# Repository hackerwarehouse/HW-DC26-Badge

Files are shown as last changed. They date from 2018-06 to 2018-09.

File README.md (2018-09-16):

# HW-DC26-Badge
This is the project page for the Hacker Warehouse electronic badge that was made for DEF CON 26.



## Badge Hardware Specs
* ESP32
* Atmel 32u4
* 96×64 Graphic Full Color OLED Display
* 14x Mini NeoPixel RGB LEDs
* 4 tactile buttons
* 8 Mb Storage
* 2x2 "[Shitty Add-on](https://hackaday.io/project/52950-defcon-26-shitty-add-ons "Shitty Add-on")" support
* Powered via 2 AA batteries or USB

## Badge Functions
* HID Arsenal
	* Ducky script compatible payloads (Windows and Linux demo payloads included)
	* Expanded ducky commands to support mouse movement and clicks
	* Static strings (yubico like)
	* Mouse jiggler (anti screensaver)
	* Time-based One-Time Password and HMAC-based One-Time Password (Google Authenticator mode /w keyboard insertion on demand)
* WiFi Tools
	* 802.11 channel activity monitor
	* Access point scanner / Open AP detector
	* Packet Monitor and Deauth sniffer
	* Can act as a client or access point
	* Webserver (edit filesystem files, trigger payloads remotely)
	* NTP client
* LED patterns and OLED graphics
* Misc. extras

## Usage Instructions
### Power Switch
In order to turn on the device, it must be powered via 2 AA batteries or USB. The main power switch is between the eyes.

### Buttons / UI


Up and Down is on the left side of the OLED, and Left and Right is on the right side of the OLED. From left most to right:  Down / Up / Left / Right

In order to go into a menu or run a program, click the right button. To exit most applications, click the left button. Some programs like the snake game require all 4 buttons so there is no way to clean exit, a power cycle is needed. 

### Keyboard and Mouse Payloads
When the badge is connected to a computer through the USB port, it can act as a HID device. The most common uses of that device class is keyboards and mice. Through use of the Ducky language and expanding on it to support mouse movement, the badge can trigger these scripts on demand. 

#### Via Hardware Menu
Navigate to the HID Arsenal menu, then select either the Windows or Linux Payloads menu option, depending on your target device. In the next submenu, there are five slots for payloads and pressing the right button triggers them. The slots are configurable via win.json and lin.json which defines the payload name and file location.

#### Via Webserver
Assuming the Webserver is running (via Server Tools -> Webserver Start), navigate to 10.0.5.1. Authenticate via the credentials on the OLED. You can remotely trigger the stored payloads or write on demand payloads via this interface. The stored payloads read the same win.json and lin.json files. 

### Static Strings
This mode is something like the yubico device. It is simply a static string that you can utilize with another password. This is a method of two factor authentication as the static string would be likely long and complex. Disclaimer: There is no security mechanism in place if someone were to obtain the hardware and this isn't a FIPS certified device.

### Mouse Jiggler
This mode is utilized if you have a device that you don't want the screen saver to be triggered. The mouse will move every few seconds in a defined pattern. This is useful if you have a device that forces a screensaver or device lock after x idle time. 

### Google Authenticator
This mode requires the badge to be connected to an access point that has internet connectivity so it can reach a time server as there is no RTC on the device itself. In the WiFi client tools menu, connect to an AP and make sure NTP is running. From there, in the HID Arsenal menu select the 'Google Auth (TOTP)' submenu. The six digit time based unique code will refresh every seconds. Press the right button to insert that set of digits automatically assuming the badge is connected through USB. 



### Webserver
Navigate to WiFi Server Tools -> Webserver Start. You can access the webserver if running an AP or if connected. The pages are protected through basic authentication, username and password generated dynamically and is provided on the screen.

### Blinky
There are 40+ LED patterns included. We've included our favorites set in a 5 second rotation. You can also trigger each type of pattern individually. 

### Other Modes
There are no hidden modes, but there are a few areas we didn't cover in this set of docs. Explore. 

## Configuration / Customization
### Settings menu in OLED UI
After feedback from last year on brightness settings, there are individual settings for OLED and LED brightness. Region setting is related to WiFi channel scanning.

### JSON configuration files
There are 4 different json files in SPIFFS. There are a couple ways to edit these files and get them loaded on the badge, but the easiest is through the webserver.
1. config.json = Main device configuration. Includes parameters such as LED and OLED brightness settings, ssid/password if connecting to a wireless client network, region information, and google auth HMAC. 
2. lin.json / win.json = Configuration files for the Linux and Windows KB/M payloads. 
3. static.json = Configuration file for the stored static strings. 

### Google Authenticator
If you do not have a 2 factor code from Google already, follow these steps to set obtain one and change your security settings: 
https://myaccount.google.com/security -> Signing into Google -> 2 Factor Authentication -> Authenticator App -> iphone -> click the 'Can't scan it' button and you will get a string of text that looks like this (and remember that your code will be different than this example):



Take that text, remove all the spaces, change the letter casing to all upper case, then 
input the text into config.json

## Compiling Instructions
These instructions will get you a copy of the project up and running on your local machine.
### Prerequisites
What things you need to install the software and how to install them
```
1. Arduino / compiler
2. SparkFun Pro Micro v3 com driver
https://learn.sparkfun.com/tutorials/pro-micro--fio-v3-hookup-guide/installing-windows
https://learn.sparkfun.com/tutorials/pro-micro--fio-v3-hookup-guide/installing-mac--linux
3. Libraries
  https://raw.githubusercontent.com/sparkfun/Arduino_Boards/master/IDE_Board_Manager/package_sparkfun_index.json
  https://github.com/adafruit/Adafruit_NeoPixel
  https://github.com/adafruit/Adafruit-GFX-Library
  https://github.com/adafruit/Adafruit_CircuitPlayground
  https://github.com/kitesurfer1404/WS2812FX
  https://github.com/me-no-dev/ESPAsyncWebServer
  https://github.com/me-no-dev/AsyncTCP
  https://github.com/bblanchon/ArduinoJson
  https://github.com/me-no-dev/arduino-esp32fs-plugin
  Manually copy the SSD_13XX and qMenuSystem folders to Arduino libraries folder. We included a snapshot of the other libraries used in case newer versions break our code.
4. 3.3v FTDI serial cable
5. and of course a Hacker Warehouse DC26 Badge
```
### Compiling / Flashing Atmel Code
* Set the board to SparkFun Pro Micro
* Set the processor as ATmega32u4 3.3v and NOT the 5v one

### Compiling / Flashing ESP Code
* Set the board to SparkFun ESP32 Thing

#### Programming through FTDI port
1. Flash the atmel with the 'atmel-esp32ftdi-pin7' code first, as this toggle pin 7 and the rx/tx switch to change the serial port communiction to the FTDI port
2. Connect FTDI cable to the board while holding the left button down (which is on the right side, top button)
3. Upload code. Speed setting doesn't really matter, we've been using 921600.
4. To put the atmel back to its original state, program 'atmel-km-relay' the code to it.

#### Programming through USB port / Atmel
Pass through programming doesn't work at the time of writing. Communication is passed through, but something is holding up the ESP32 from fully going into the programming mode

### Uploading SPIFFS files
The keyboard/mouse payloads, configuration files, webserver files are all files that are loaded into a special section in storage marked as SPIFFS. While still having pin 7 set to allow for the FTDI connection, use the 'ESP32 Sketch Data Upload' function in the tools menu. This will compress and compile all the files in the 'data' folder, and upload it. 

## Expanding on your own
### Adding to menu
* See files HW-DC26-Badge.ino and mainmenu.h
* Look at the main switch statement in the .ino file
* Look any of the mainmenu.h examples for how it corresponds to the display

### Button mapping / Escape code
* See files HW-DC26-Badge.ino and blinky.cpp 
* Button mapping is in the beginning of the .ino file
* Look at the LED_Flashlight function for an example of button usage and how to quit the loop and go back to main menu

## Background / timeline of badge development
* Second custom hardware / electronics project trying to improve upon the things we learned from last year
	* Changed from the ESP8266 to the newer ESP32 so we could leverage prior code and focus on enhancements 
	* Added an LDO regulator so badge or connected computer doesn't freak out on voltage
* 3 hardware revisions = 2 prototype runs = 4-5 months
	* The hardware revisions this year were minor in comparison to last year. It was mainly due to the 2x2 Shitty Add-on and orientation of the connector
	* Tried to start earlier (lesson learned last year) but scheduling conflicts put us back to essentially the same timeline as last year
* 5 week code sprint before code needing to be frozen for mass badge flashing
	* This was a massive improvement from last year from a time / rush perspective
	* Still wanted to add more into it such as BLE, but ram out of storage and ram. 

## Authors / Contributors
* **Garrett Gee**

## Acknowledgments
* Hat tip to anyone who's code was used, looked at, referenced, etc
* All the supporters of this project

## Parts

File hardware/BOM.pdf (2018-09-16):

Quantity | Description | Part Number | Alternative Part Number | Reference Designator
2 | 22PF 50V NP0 0603 Capacitor | CL10C220JB8NNNC | C1608C0G1H220G080AA | C2, C3
2 | 10uf Tantalum Capacitor 1206 16V 20% | F931C106MAAAJ6 | F931C106MAA | C4, C8
1 | 4.7UF 16V X5R 0603 | C1608X6S1C475K080AC | | C46
4 | 10uF 25V 20% 0603 Capacitor | CL10A106MA8NRNC | | C6, C9, C10, C24
1 | .01uf/10nf 100V 0603 10% Capacitor | CL10B103KC8NNNC | | C20
5 | 1uf 16V 10% 0603 Capacitor | CC0603MRY5V6BB105 | CL10A105KO8NNNC | C1, C29, C44, C45, C47
22 | 0.1uf 25V 10% 0603 Capacitor | 06033C104KAZ2A | CL10B104KA8NNNC | C5, C7, C21, C23, C25, C26, C27, C28, C30, C31, C32, C33, C34, C35, C36, C37, C38, C39, C40, C41, C42, C43
1 | 3.3nf 16V 10% 0603 Capacitor | VJ0603Y332KXJCW1BC | | C19
1 | 100pf/0.1nf 100V 0603 Capacitor | GRM1885C2A101JA01D | | C22
2 | 10pF Â±0.25pF 50V Ceramic Capacitor C0G, NP0 0603 | C1608C0G1H100C080AA | | C13, C16
1 | 5.6pF Ceramic Capacitor +-0.5pF 50V 0603 | CL10C5R6DB8NNNC | | C11
2 | CAP CER 15PF 50V C0G/NPO 0603 | CC0603JRNPO9BN150 | | C14, C15
1 | CAP CER 2.4PF 50V C0G/NP0 0603 | CL10C2R4CB8NNNC | | C12
2 | CAP CER 270PF 50V X7R 0603 | CL10B271KB8NNNC | | C17, C18
1 | SS1P3L Schottky Diode 30V 1A | SS1P3L-M3/84A | | D3
2 | DIODE SCHOTTKY 40V 1A SOD123 | B140HW-7 | | D2, D5
1 | Diode Standard 75V 150mA SOD-323F | 1N914BWS | | D1
14 | 3535 RGB Addressable LED | SK6812MINI | | LED1, LED2, LED3, LED4, LED5, LED6, LED7, LED8, LED9, LED10, LED11, LED12, LED13, LED14
1 | DPDT Slide Switch (On/Off) SMT | AYZ0202AGRLC | | S1
4 | Black Momentary Push Button - SMD | TL3301NF100QG | | U$1, U$2, U$3, U$4
1 | USB Micro-B RECPT SMD Connector | 10118194-0001LF | | U$6
1 | Battery Holder 2-AA TH | BC2AAPC | | U$5
2 | 2x2 Pin 4P 2.54mm Double Row Female Straight Header Pitch Socket Pin Strip | | | JP1, JP2
1 | ATMEGA32U4-MU Microcontroller QFN | ATMEGA32U4-MU | | U4
1 | LED Driver Regulator 1A SOT23-5 | FAN5331SX | | U1
1 | IC REG LINEAR 3.3V 500MA SOT223 | MIC5209-3.3YS-TR | | U$7
2 | IC MUX/DEMUX 2X1 6TSSOP | 74LVC1G3157GW,125 | | U$8, U$9
1 | ESP3212 | ESP3212 | | U2
1 | IC OR CTRLR SRC SELECT 8SON | TPS2113ADRBR | | U$10
1 | IC FLASH 64MBIT SPI 8SOIC W25Q64JVSSIM TR | W25Q64JVSSIM TR | | U5
1 | 10 uH Inductor 1.8A 5028 | SRU5018-100Y | | L1
1 | FIXED IND 2.7NH 300MA 100 MOHM | HK16082N7S-T | | L2
1 | 0.95 inch (96 x 64) Pixel Full Color Passive OLED LCD | UG-9664HDDAG01 | | LCD1
3 | 100K Resistor 0603 1/10W 5% | RC0603JR-07100KL | | R2, R6, R12

## Hacker Warehouse 2018 DC26 Badge v1.1 BOM

Quantity | Description | Part Number | Alternative Part Number | Reference Designator
1 | 1K OHM 5% 1/10W 0603 Resistor | ERJ-3GEYJ102V | RC0603JR-071KL | R13
6 | 10K Resisitor 0603 1/10W 5% | RC0603JR-0710KL | | R1, R3, R5, R7, R8, R10
1 | 1M Resistor 0603 1/10W 1% | RC0603FR-071ML | | R4
2 | 22 ohm Resistor 0603 1/10W 5% | RC0603JR-0722RL-S | | R14, R15
2 | RES SMD 20K OHM 1% 1/10W 0603 | RC0603FR-0720KL | | R9, R11
1 | 8.0 MHz Crystal 5 mm x 3.2 mm | ABM3B-8.000MHZ-B2-T | | Y1
1 | 32.768 KHz Crystal FC-135 32.7680KA-A3 | ABS07-32.768KHZ-T | FC-135 32.7680KA-A3 | X2
1 | Crystal 26MHz 3.2 x 2.5 | TSX-3225 26.0000MF09Z-AC0 | | Y2

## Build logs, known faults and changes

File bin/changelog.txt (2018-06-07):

HW-DC26-Badge-20180603.bin
 New
  - Webserver via ESPAsyncWebServer and AsyncTCP libraries
  - SPIFFS live editor / file upload via webserver
  - Firmware update via webserver
  - Live Keyboard/Mouse payload via webserver
  - Stored Keyboard/Mouse payloads can be triggered via webserver
 Updates / Tweaks
  - KB injection call does basic checks first before attempting to run
  - Early Supporters list
 Known Bugs / Limitations
  - MINOR: NTP_OFFSET is an int and some timezone offsets are greater than that size. NTP library itself needs fixing. Doesn't impact TOTP
  - MINOR: SPIFFS file writing /w file name length and directories. Doesn't impact demo payloads
  - MINOR: max file name length for payloads is 40 chars
  - MINOR: dynamic menu names have max length of 15 chars
  - ?    : stability due to lack of ram available for large tasks (SPIFFS live editor)
 Compile notes:
   Sketch uses 843890 bytes of program storage space. Maximum is 1310720 bytes.
   Global variables use 43216 bytes (14%) of dynamic memory, leaving 251696 bytes for local variables. Maximum is 294912 bytes.

HW-DC26-Badge-20180522.bin
 New
  - Custom KB injection naming/ordering in menu via json files
 Updates / Tweaks
  - Moved static strings configuration to its own json file
 Fixed
  - Static strings injection
 Known Bugs / Limitations
  - MINOR: NTP_OFFSET is an int and some timezone offsets are greater than that size. NTP library itself needs fixing. Doesn't impact TOTP
  - MINOR: SPIFFS file writing /w file name length and directories. Doesn't impact demo payloads
  - MINOR: max file name length for payloads is 40 chars
  - MINOR: dynamic menu names have max length of 15 chars
 Compile notes:
   Sketch uses 764814 bytes of program storage space.
   Global variables use 42696 bytes (14%) of dynamic memory, leaving 252216 bytes for local variables. Maximum is 294912 bytes.

HW-DC26-Badge-20180515.bin
 New
  - AP start/stop/info display service
  - Static strings kb injection module /w custom names via config.json
 Updates / Tweaks
  - Google Auth code can now be inserted for user via usb kb injection if pressing right button while in app
  - Graphic image updates
  - Change loop structure on majority of functions
  - Ducky compatible parser for kb injection
  - Standardized mouse button and movement triggers
 Known Bugs / Limitations
  - MINOR: NTP_OFFSET is an int and some timezone offsets are greater than that size. NTP library itself needs fixing. Doesn't impact TOTP
  - MINOR: SPIFFS file writing /w file name length and directories. Doesn't impact demo payloads
 Compile notes:
   Sketch uses 762986 bytes of program storage space.
   Global variables use 42064 bytes (14%) of dynamic memory, leaving 252848 bytes for local variables. Maximum is 294912 bytes.

HW-DC26-Badge-20180508.bin
 New
  - Time based One Time Password (TOTP) - make sure NTP is running for clock sync
  - Google Authenticator using TOTP via user key in spiffs
 Fixed
  - Internet connection logic
  - NTP server connection issue
  - Flashlight lowest mode
 Known Bugs / Limitations
  - MINOR: NTP_OFFSET is an int and some timezone offsets are greater than that size. NTP library itself needs fixing. Doesn't impact TOTP
 Compile notes:
   Sketch uses 756498 bytes of program storage space. 
   Global variables use 41832 bytes (14%) of dynamic memory, leaving 253080 bytes for local variables. Maximum is 294912 bytes.

HW-DC26-Badge-20180506.bin
 New
  - Keyboard sequence pass through from esp32 to 32u4 for keyboard injection on computer
  - Mouse sequence pass through from esp32 to 32u4 for mouse injection on computer
  - NTP client - pacific time default for Las Vegas
 Updates / Tweaks
  - File and menu organization to support feature expansion
  - Internet ssid / password settings in spiffs
  - Optimized connection attempts to internet ssid
 Compile notes:
   Sketch uses 754658 bytes of program storage space.
   Global variables use 41648 bytes (14%) of dynamic memory, leaving 253264 bytes for local variables. Maximum is 294912 bytes.

HW-DC26-Badge-20180505.bin
 Updates / Tweaks
  - Flashlight now starts at lowest setting
  - Snake game added back in
  - Button echo added back in
  - Keyboard demo added back in
 Fixed
  - String importing on json config file
 Compile notes:
   Sketch uses 743770 bytes of program storage space. 
   Global variables use 41452 bytes (14%) of dynamic memory, leaving 253460 bytes for local variables. Maximum is 294912 bytes.

HW-DC26-Badge-20180504.bin
 Updates / Tweaks
  - Added back in Channel AP Scanner
  - Display code logic
  - Added back in and updated packet / deauth sniffer
 Compile notes:
   Sketch uses 736418 bytes of program storage space.
   Global variables use 41260 bytes (13%) of dynamic memory, leaving 253652 bytes for local variables. Maximum is 294912 bytes.

HW-DC26-Badge-20180503.bin
 New
  - spiffs for configuration save. removed eeprom versions as esp32 eeprom support is currently buggy
  - Firmware OTA update
 Updates / Tweaks
  - Added back in AP Scanner
  - Split out oled and led brightness settings
  - Changed UX on oled and led brightness settings for quicker user feedback
 Fixed
  - Oled on power on
  - LEDs that randomly stay on at power on
 Compile notes:
   Sketch uses 726558 bytes of program storage space. 
   Global variables use 40508 bytes (13%) of dynamic memory, leaving 254404 bytes for local variables. Maximum is 294912 bytes.

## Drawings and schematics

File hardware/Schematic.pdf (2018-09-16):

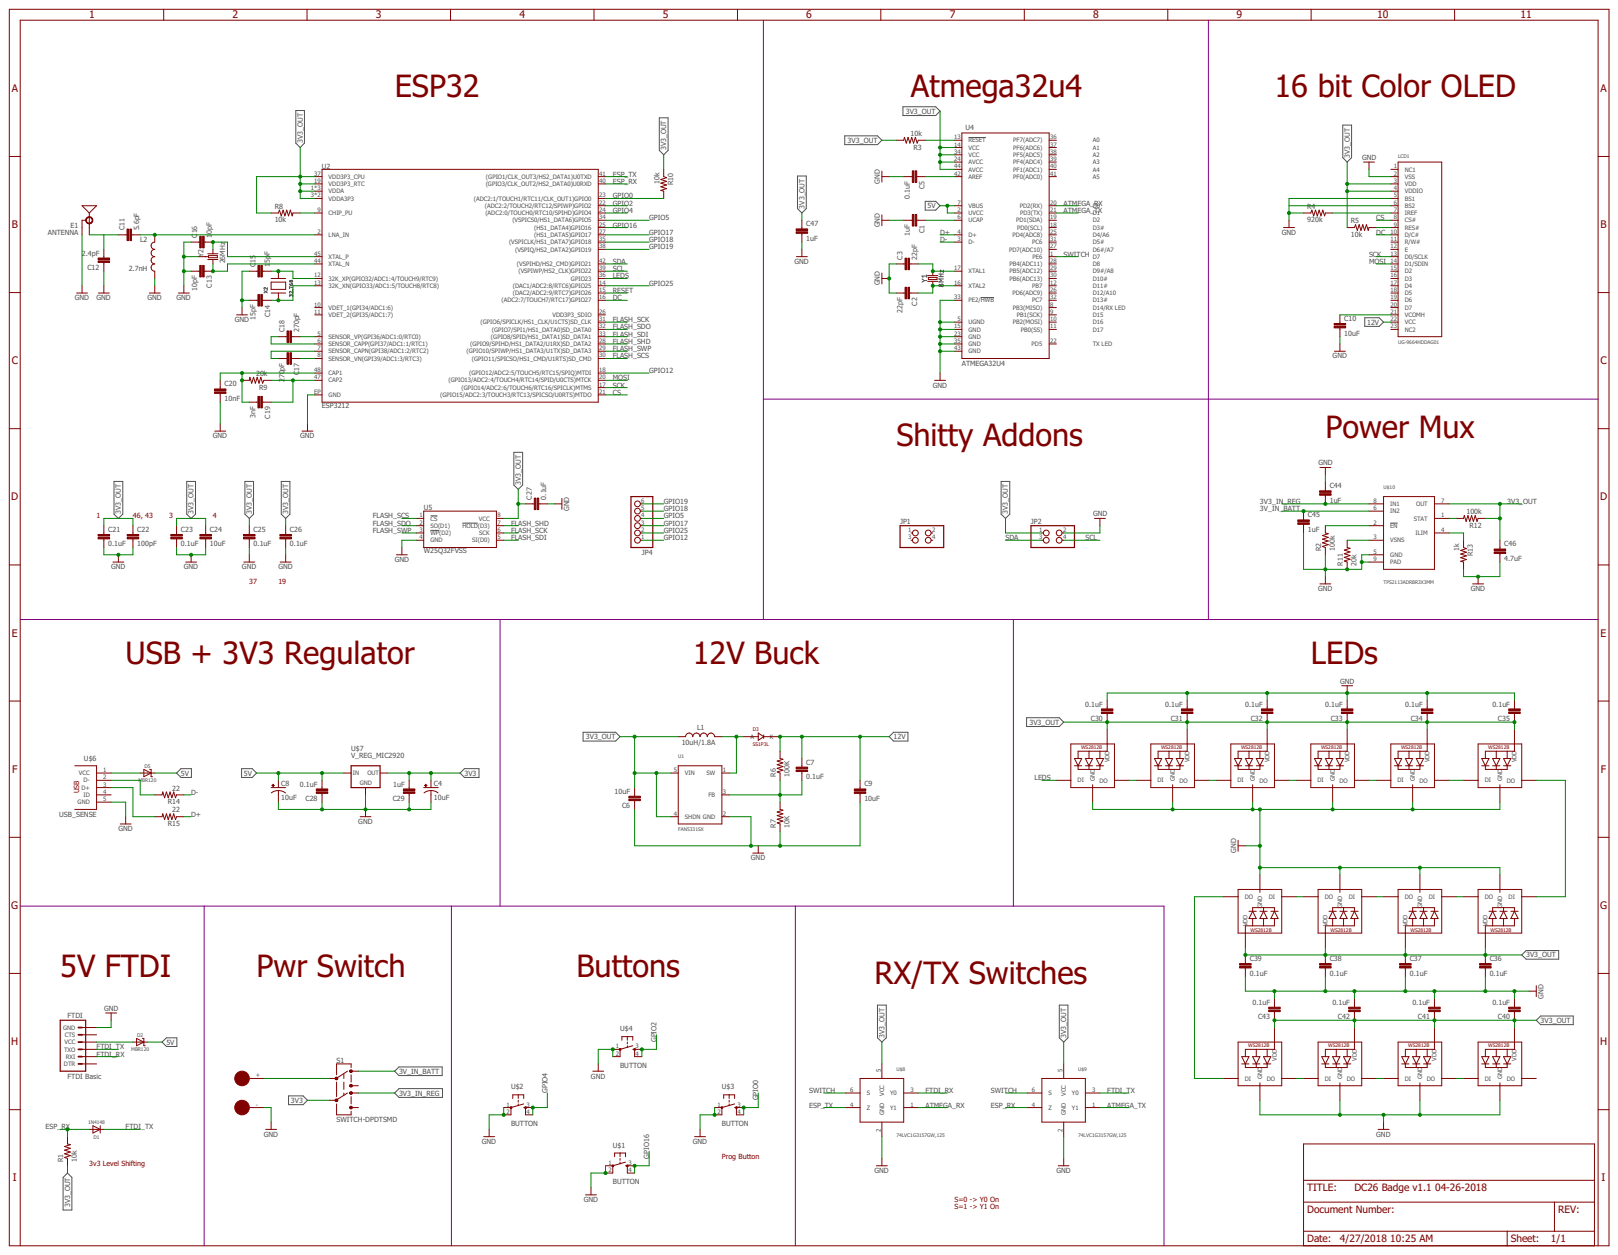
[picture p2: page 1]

ESP32 | Atmega32u4 | 16 bit Color OLED

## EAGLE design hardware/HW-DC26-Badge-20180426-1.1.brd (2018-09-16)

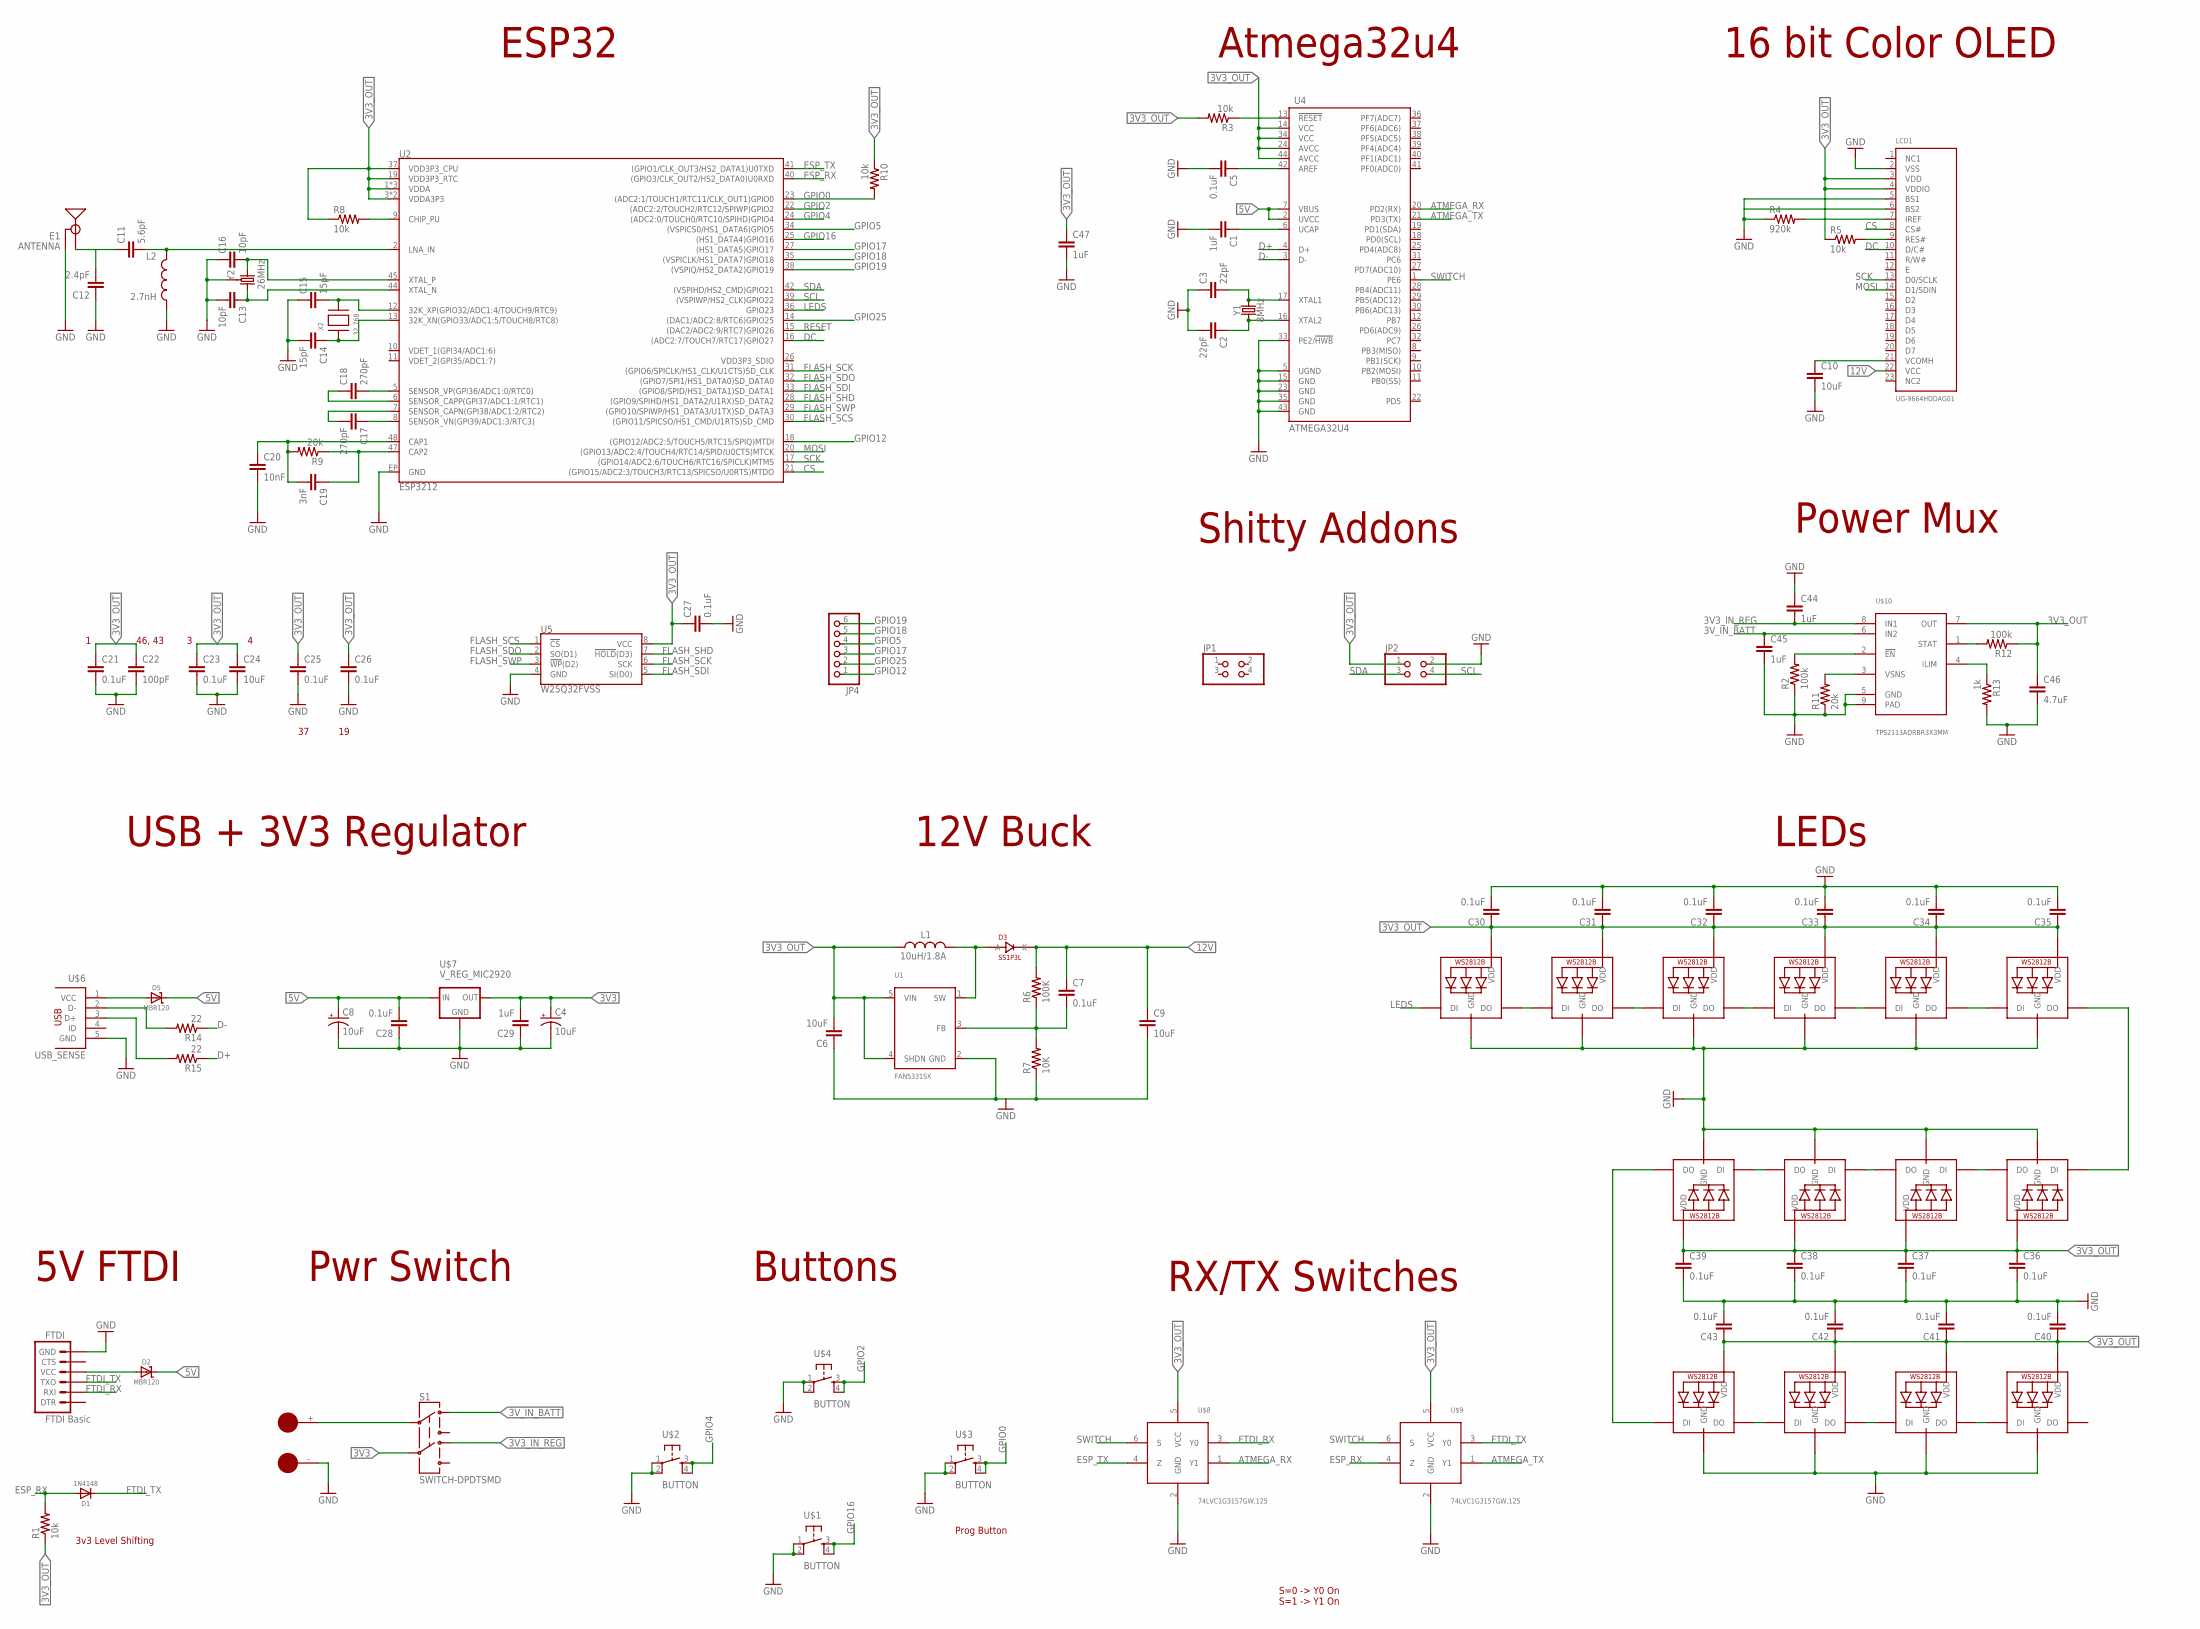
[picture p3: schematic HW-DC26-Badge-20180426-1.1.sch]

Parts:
C1, C29, C44, C45, C47: 1uF; CAP0603
C2, C3: 22pF; CAP0603
C4, C8: 10uF; EIA3216
C5, C7, C21, C23, C25, C26, C27, C28, C30, C31, C32, C33, C34, C35, C36, C37, C38, C39, C40, C41, C42, C43: 0.1uF; CAP0603
C6, C9, C10, C24: 10uF; CAP0603
C11: 5.6pF; CAP0603
C12: 2.4pF; CAP0603
C13, C16: 10pF; CAP0603
C14, C15: 15pF; CAP0603
C17, C18: 270pF; CAP0603
C19: 3nF; CAP0603
C20: 10nF; CAP0603
C22: 100pF; CAP0603
C46: 4.7uF; CAP0603
D1: 1N4148; SOD-323
D2, D5: MBR120; SOD-123
D3: SS1P3L; DO220AAL
E1: ANTENNA; TRACE_ANTENNA_2.4GHZ_25.7MM_TUNED
FTDI: FTDI Basic; 1X06
JP1, JP2: PINHD-2X2; 2X02
JP4: PINHD-1X6; 1X06
L1: 10uH/1.8A; SRU5028
L2: 2.7nH; 0603
LCD1: UG-9664HDDAG01; UG-9664HDDAG01_WRAPAROUND
LED1, LED2, LED3, LED4, LED5, LED6, LED7, LED8, LED9, LED10, LED11, LED12, LED13, LED14: WS2812B3535; LED3535
R1, R3, R5, R8, R10: 10k; RES-0603
R2, R12: 100k; RES-0603
R4: 920k; RES-0603
R6: 100K; RES-0603
R7: 10K; RES-0603
R9, R11: 20k; RES-0603
R13: 1k; RES-0603
R14, R15: 22; RES-0603
S1: SWITCH-DPDTSMD; AYZ0202
U1: FAN5331SX; SOT23-5
U2: ESP3212; QFN48-0.4MM
U4: ATMEGA32U4; QFN-44-NOPAD_1:1-OUTFAKES
U5: W25Q32FVSS; SOIC-8
U$1, U$2, U$3, U$4: BUTTON
U$5: BAT_HOLD; AA
U$6: USB_SENSE; USB-MICRO-TH-SUPPORT
U$7: V_REG_MIC2920; SOT223
U$8, U$9: 74LVC1G3157GW,125; SOT-363
U$10: TPS2113ADRBR3X3MM; 8-VDFN
X2: 32.768; XTAL3215
Y1: 8MHz; CRYSTAL-SMD-5X3.2-4PAD
Y2: 26MHz; CRYSTAL-SMD-3.2X2.5

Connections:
3V3: C4.A (+), C29.2, S1.5, U$7.3 (OUT)
3V3_IN_REG: C44.2, S1.4, U$10.8 (IN1)
3V3_OUT: C6.2, C21.1, C22.1, C23.1, C24.1, C25.1, C26.1, C27.1, C30.1, C31.1, C32.1, C33.1, C34.1, C35.1, C36.1, C37.1, C38.1, C39.1, C40.1, C41.1, C42.1, C43.1, C46.1, C47.1, JP2.1, L1.1, LCD1.3 (VDD), LCD1.4 (VDDIO), LED1.2 (VDD), LED2.2 (VDD), LED3.2 (VDD), LED4.2 (VDD), LED5.2 (VDD), LED6.2 (VDD), LED7.2 (VDD), LED8.2 (VDD), LED9.2 (VDD), LED10.2 (VDD), LED11.2 (VDD), LED12.2 (VDD), LED13.2 (VDD), LED14.2 (VDD), R1.1, R3.2, R5.1, R8.1, R10.1, R12.1, U1.4 (SHDN), U1.5 (VIN), U2.1 (VDDA), U2.3 (VDDA3P3), U2.4 (VDDA3P3), U2.19 (VDD3P3_RTC), U2.37 (VDD3P3_CPU), U2.43 (VDDA), U2.46 (VDDA), U4.14 (VCC), U4.24 (AVCC), U4.34 (VCC), U4.44 (AVCC), U5.8 (VCC), U$8.5 (VCC), U$9.5 (VCC), U$10.7 (OUT)
3V_IN_BATT: C45.1, S1.1, U$10.6 (IN2)
5V: C8.A (+), C28.2, D2.C, D5.C, U4.2 (UVCC), U4.7 (VBUS), U$7.1 (IN)
12V: C7.1, C9.1, D3.P$1 (K), LCD1.22 (VCC), R6.2
ATMEGA_RX: U4.20 (PD2(RX)), U$8.1 (Y1)
ATMEGA_TX: U4.21 (PD3(TX)), U$9.1 (Y1)
CS: LCD1.8 (CS#), U2.21 ((GPIO15/ADC2:3/TOUCH3/RTC13/SPICSO/U0RT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)
D+: R15.1, U4.4 (D+)
D-: R14.1, U4.3 (D-)
DC: LCD1.10 (D/C#), U2.16 ((ADC2:7/TOUCH7/RTC17)GPIO27)
ESP_RX: D1.A, R1.2, U2.40 ((GPIO3/CLK_OUT2/HS2_DATA0)U0RXD), U$9.4 (Z)
ESP_TX: U2.41 ((GPIO1/CLK_OUT3/HS2_DATA1)U0TXD), U$8.4 (Z)
FLASH_SCK: U2.31 ((GPIO6/SPICLK/HS1_CLK/U1CTS)SD_CLK), U5.6 (SCK)
FLASH_SCS: U2.30 ((GPIO11/SPICSO/HS1_CMD/U1RTS)SD_CMD), U5.1 (!CS!)
FLASH_SDI: U2.33 ((GPIO8/SPID/HS1_DATA1)SD_DATA1), U5.5 (SI(D0))
FLASH_SDO: U2.32 ((GPIO7/SPI1/HS1_DATA0)SD_DATA0), U5.2 (SO(D1))
FLASH_SHD: U2.28 ((GPIO9/SPIHD/HS1_DATA2/U1RX)SD_DATA2), U5.7 (!HOLD!(D3))
FLASH_SWP: U2.29 ((GPIO10/SPIWP/HS1_DATA3/U1TX)SD_DATA3), U5.3 (!WP!(D2))
FTDI_RX: FTDI.2 (RXI), U$8.3 (Y0)
FTDI_TX: D1.C, FTDI.3 (TXO), U$9.3 (Y0)
GND: C1.2, C2.2, C3.1, C4.C (-), C5.2, C6.1, C8.C (-), C9.2, C10.2, C12.1, C13.2, C14.2, C15.1, C16.1, C20.2, C21.2, C22.2, C23.2, C24.2, C25.2, C26.2, C27.2, C28.1, C29.1, C30.2, C31.2, C32.2, C33.2, C34.2, C35.2, C36.2, C37.2, C38.2, C39.2, C40.2, C41.2, C42.2, C43.2, C44.1, C45.2, C46.2, C47.2, E1.GND, E1.GND2 (GND), FTDI.6 (GND), JP2.2, L2.2, LCD1.2 (VSS), LCD1.5 (BS1), LED1.4 (GND), LED2.4 (GND), LED3.4 (GND), LED4.4 (GND), LED5.4 (GND), LED6.4 (GND), LED7.4 (GND), LED8.4 (GND), LED9.4 (GND), LED10.4 (GND), LED11.4 (GND), LED12.4 (GND), LED13.4 (GND), LED14.4 (GND), R2.1, R4.1, R7.1, R11.1, R13.2, U1.2 (GND), U2.EP (GND), U4.5 (UGND), U4.15 (GND), U4.23 (GND), U4.33 (PE2/!HWB), U4.35 (GND), U4.43 (GND), U5.4 (GND), U$1.1, U$1.2, U$2.1, U$2.2, U$3.1, U$3.2, U$4.1, U$4.2, U$5.-, U$6.5 (GND), U$7.2 (GND), U$7.4 (GND), U$8.2 (GND), U$9.2 (GND), U$10.5 (GND), U$10.9 (PAD), Y2.2 (GND), Y2.4 (GND)
GPIO0: R10.2, U2.23 ((ADC2:1/TOUCH1/RTC11/CLK_OUT1)GPIO0), U$3.3, U$3.4
GPIO2: U2.22 ((ADC2:2/TOUCH2/RTC12/SPIWP)GPIO2), U$4.3, U$4.4
GPIO4: U2.24 ((ADC2:0/TOUCH0/RTC10/SPIHD)GPIO4), U$2.3, U$2.4
GPIO5: JP4.4, U2.34 ((VSPICS0/HS1_DATA6)GPIO5)
GPIO12: JP4.1, U2.18 ((GPIO12/ADC2:5/TOUCH5/RTC15/SPIQ)MTDI)
GPIO16: U2.25 ((HS1_DATA4)GPIO16), U$1.3, U$1.4
GPIO17: JP4.3, U2.27 ((HS1_DATA5)GPIO17)
GPIO18: JP4.5, U2.35 ((VSPICLK/HS1_DATA7)GPIO18)
GPIO19: JP4.6, U2.38 ((VSPIQ/HS2_DATA2)GPIO19)
GPIO25: JP4.2, U2.14 ((DAC1/ADC2:8/RTC6)GPIO25)
LEDS: LED5.1 (DI), U2.36 (GPIO23)
MOSI: LCD1.14 (D1/SDIN), U2.20 ((GPIO13/ADC2:4/TOUCH4/RTC14/SPID/U0CTS)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)
unnamed: C3.2, U4.17 (XTAL1), Y1.3 (2)
unnamed: R3.1, U4.13 (!RESET)
unnamed: C1.1, U4.6 (UCAP)
unnamed: C5.1, U4.42 (AREF)
unnamed: R14.2, U$6.2 (D-)
unnamed: C10.1, LCD1.21 (VCOMH)
unnamed: D3.P$2 (A), L1.2, U1.1 (SW)
unnamed: C2.1, U4.16 (XTAL2), Y1.1
unnamed: LED1.1 (DI), LED14.3 (DO)
unnamed: C7.2, R6.1, R7.2, U1.3 (FB)
unnamed: LCD1.7 (IREF), R4.2
unnamed: S1.2, U$5.+
unnamed: R8.2, U2.9 (CHIP_PU)
unnamed: C16.2, U2.45 (XTAL_P), Y2.1
unnamed: C11.1, C12.2, E1.ANT (SIGNAL)
unnamed: LED1.3 (DO), LED2.1 (DI)
unnamed: D2.A, FTDI.4 (VCC)
unnamed: LED5.3 (DO), LED6.1 (DI)
unnamed: C19.2, C20.1, R9.2, U2.48 (CAP1)
unnamed: C11.2, L2.1, U2.2 (LNA_IN)
unnamed: C13.1, U2.44 (XTAL_N), Y2.3 (2)
unnamed: C19.1, R9.1, U2.47 (CAP2)
unnamed: C15.2, U2.12 (32K_XP(GPIO32/ADC1:4/TOUCH9/RTC9)), X2.P$2
unnamed: C14.1, U2.13 (32K_XN(GPIO33/ADC1:5/TOUCH8/RTC8)), X2.P$1
unnamed: C18.2, U2.5 (SENSOR_VP(GPI36/ADC1:0/RTC0))
unnamed: C18.1, U2.6 (SENSOR_CAPP(GPI37/ADC1:1/RTC1))
unnamed: C17.2, U2.7 (SENSOR_CAPN(GPI38/ADC1:2/RTC2))
unnamed: C17.1, U2.8 (SENSOR_VN(GPI39/ADC1:3/RTC3))
unnamed: D5.A, U$6.1 (VCC)
unnamed: LED6.3 (DO), LED7.1 (DI)
unnamed: LED7.3 (DO), LED8.1 (DI)
unnamed: LED8.3 (DO), LED9.1 (DI)
unnamed: LED9.3 (DO), LED11.1 (DI)
unnamed: LED11.3 (DO), LED13.1 (DI)
unnamed: LED10.1 (DI), LED13.3 (DO)
unnamed: LED10.3 (DO), LED12.1 (DI)
unnamed: LED12.3 (DO), LED14.1 (DI)
unnamed: LED2.3 (DO), LED3.1 (DI)
unnamed: LED3.3 (DO), LED4.1 (DI)
unnamed: R15.2, U$6.3 (D+)
unnamed: R2.2, U$10.2 (!EN)
unnamed: R11.2, U$10.3 (VSNS)
unnamed: R12.2, U$10.1 (STAT)
unnamed: R13.1, U$10.4 (ILIM)
RESET: LCD1.9 (RES#), R5.2, U2.15 ((DAC2/ADC2:9/RTC7)GPIO26)
SCK: LCD1.13 (D0/SCLK), U2.17 ((GPIO14/ADC2:6/TOUCH6/RTC16/SPICLK)MTMS)
SCL: JP2.4, U2.39 ((VSPIWP/HS2_CLK)GPIO22)
SDA: JP2.3, U2.42 ((VSPIHD/HS2_CMD)GPIO21)
SWITCH: U4.1 (PE6), U$8.6 (S), U$9.6 (S)

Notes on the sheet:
ESP32
Atmega32u4
16 bit Color OLED
USB + 3V3 Regulator
5V FTDI
12V Buck
Pwr Switch
Buttons
Shitty Addons
LEDs
S=0 -> Y0 On S=1 -> Y1 On
RX/TX Switches
46, 43
Power Mux
3v3 Level Shifting
Prog Button

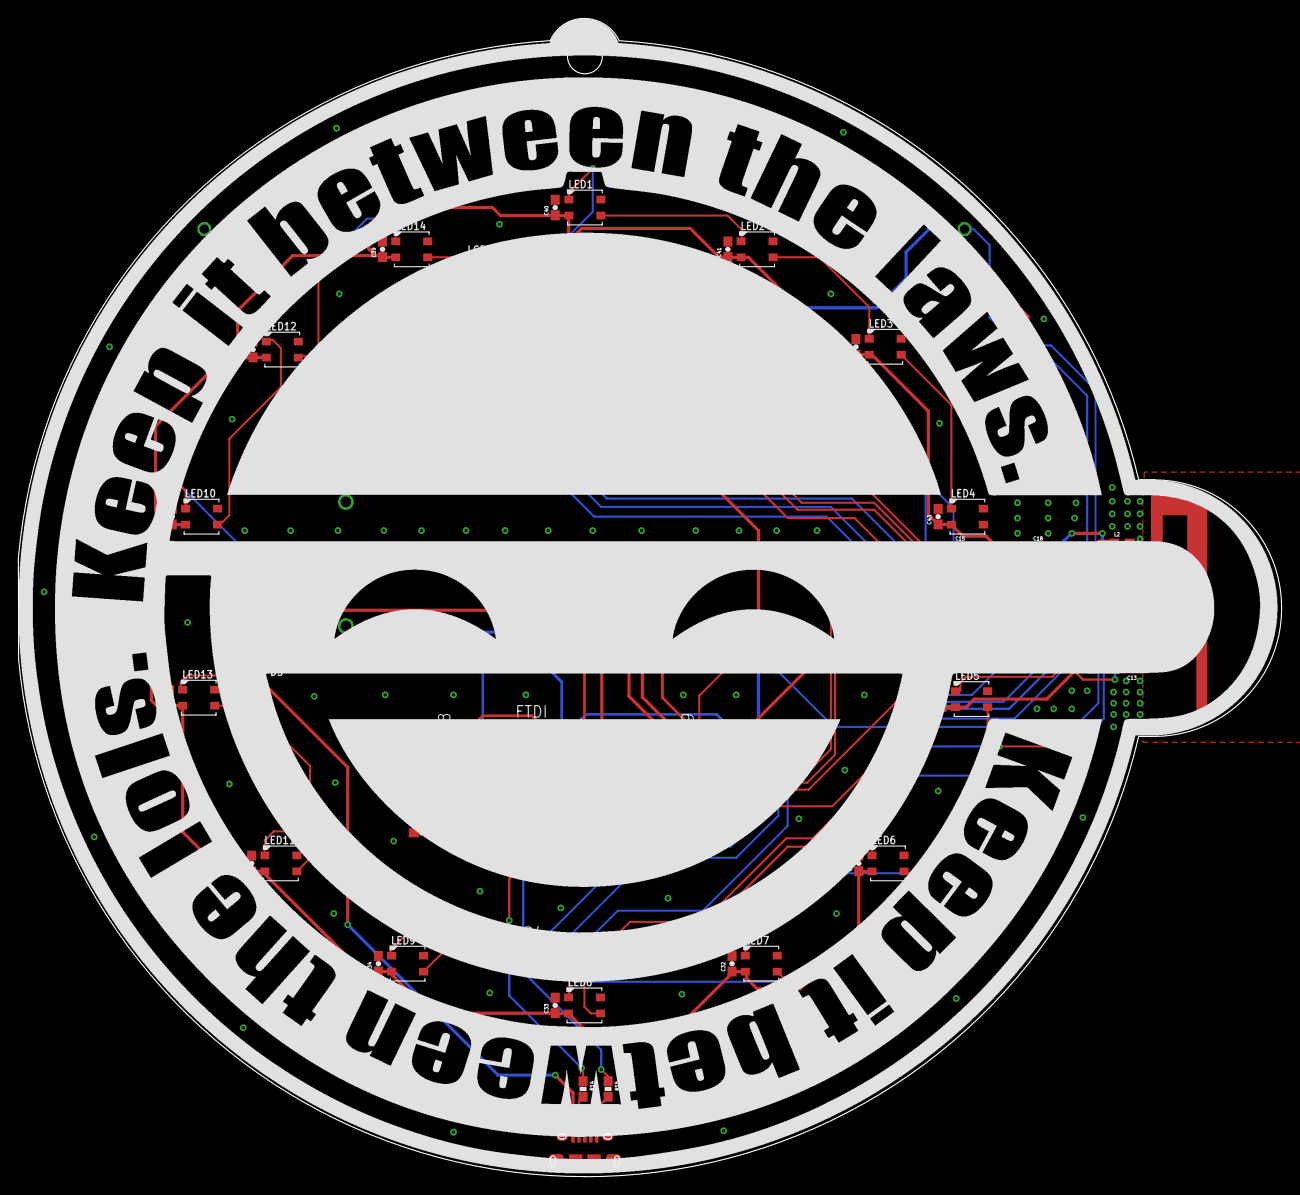
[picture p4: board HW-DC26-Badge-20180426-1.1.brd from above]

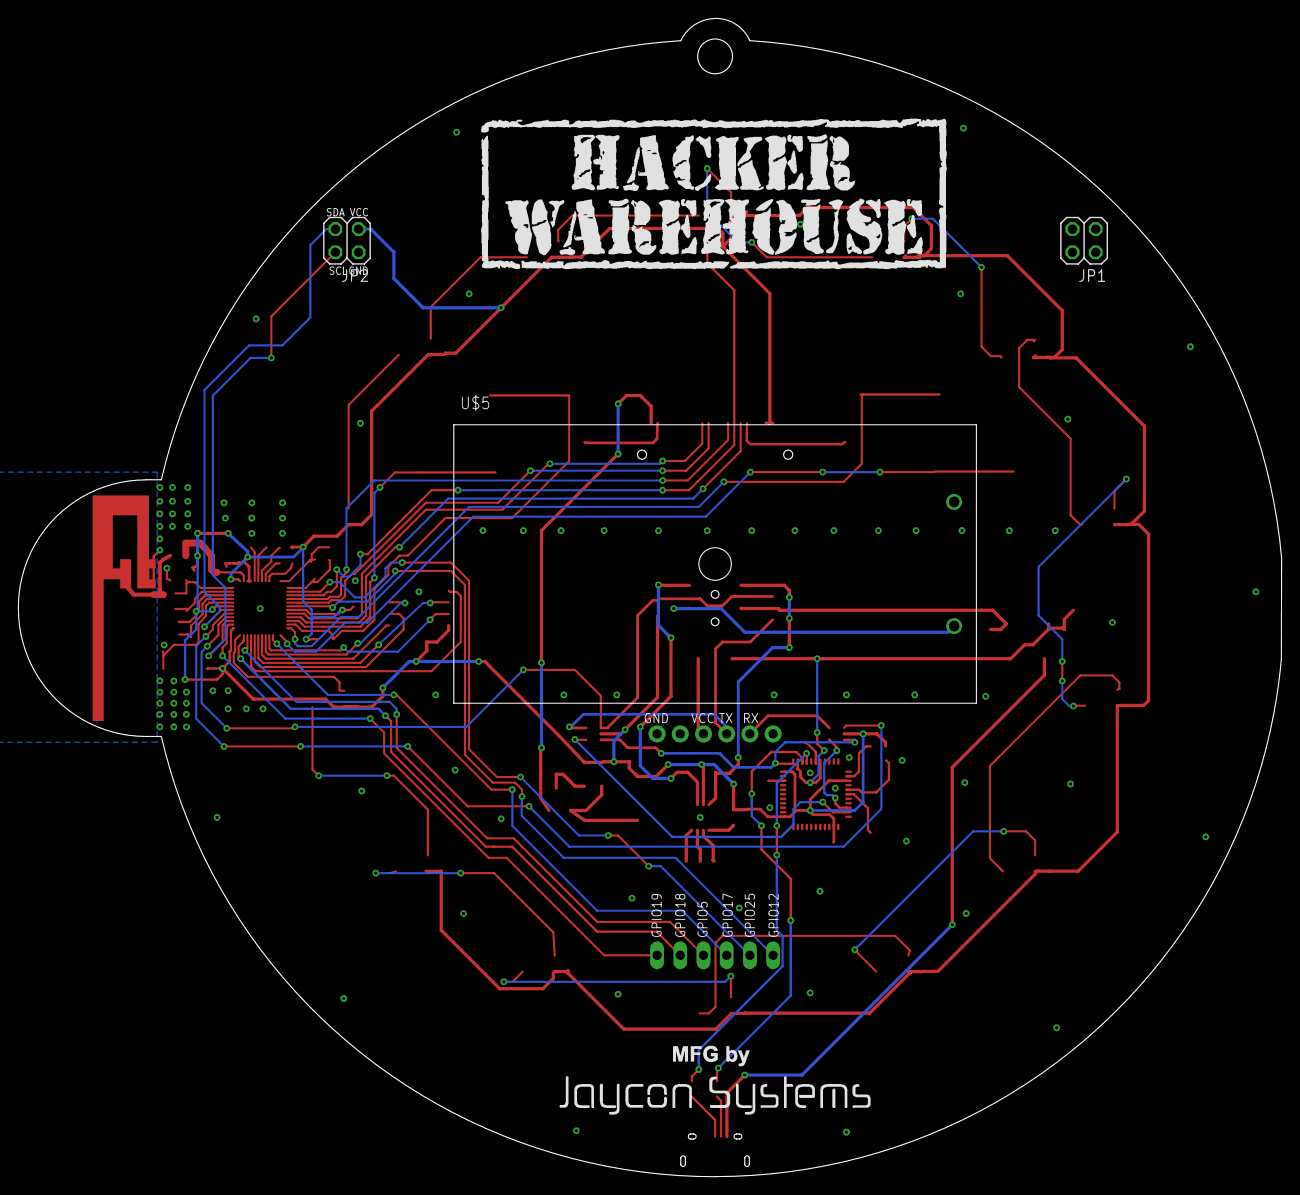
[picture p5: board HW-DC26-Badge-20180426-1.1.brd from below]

Board: 2 copper layers, 138.3 x 126.8 mm, 106 parts (3 on the bottom side), 84 nets.

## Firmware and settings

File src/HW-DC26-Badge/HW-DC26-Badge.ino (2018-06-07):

#ifdef __AVR__
  #include <avr/power.h>
#endif
#include "FS.h"
#include "SPIFFS.h"
#include <SPI.h>
#include <WiFi.h>

#include <Adafruit_NeoPixel.h>
#include <qMenuDisplay.h>
#include <qMenuSystem.h>
#include <SSD_13XX.h>
#include <WS2812FX.h>

#include "about.h"
#include "blinky.h"
#include "core.h"
#include "debug.h"
#include "extras.h"
#include "graphics.h"
#include "hidarsenal.h"
#include "mainmenu.h"
#include "settings.h"
#include "wifi-client.h"
#include "wifi-pkt1.h"
#include "wifi-scanner.h"
#include "wifi-server.h"

Adafruit_NeoPixel pixels = Adafruit_NeoPixel(NUMPIXELS, PIN, NEO_GRB + NEO_KHZ800);
WS2812FX ws2812fx = WS2812FX(NUMPIXELS, PIN, NEO_GRB + NEO_KHZ800);
SSD_13XX mydisp( /*cs*/ 15, /*dc*/ 27, /*rst*/ 26);
qMenuSystem menu=qMenuSystem(&mydisp);

const byte left = 0; 
const byte down = 16; 
const byte right = 2; 
const byte up = 4;  

volatile byte btncounter = 0;
volatile byte btnid  = 0;
byte appmode = 0;

volatile byte region_id = 1;
volatile byte oledbright;
volatile byte ledsbright;
String ISSID;
String IPSWD;
int NTP_OFFSET;
String GOOGLEAUTH;
byte region_unlocked = 0;

long debouncing_time = 250;
unsigned long last_micros = 0;

void UP(){
  if((long)(micros() - last_micros) >= debouncing_time * 1000) {
    if (appmode){      
    }
    else {
      btncounter ++;
    }
    btnid = 3;
    last_micros = micros();
  }
}

void DOWN(){
  if((long)(micros() - last_micros) >= debouncing_time * 1000) 
  {
    if (appmode){
    }
    else {
      btncounter ++;
    }
    btnid = 2;
    last_micros = micros();
  }
}

void RIGHT(){
  if((long)(micros() - last_micros) >= debouncing_time * 1000) {
    if (appmode){
    }
    else {
      btncounter ++;
    }
    btnid = 1;
    last_micros = micros();
  }
}

void LEFT(){
  if((long)(micros() - last_micros) >= debouncing_time * 1000) {
    if (appmode){
    }
    else {
      btncounter ++;
    }
    btnid = 4;
    last_micros = micros();
  }
}

void setup()
{ 
  SPI.begin( /*CLK*/ 14, /*MISO*/ 12, /*MOSI*/ 13);
  SPIFFS.begin();
  mydisp.begin();
  
  pinMode(up, INPUT_PULLUP);
  pinMode(down, INPUT_PULLUP);
  pinMode(right, INPUT_PULLUP);
  pinMode(left, INPUT);           //External pulldown resistor (required for programming)

  attachInterrupt(digitalPinToInterrupt(up), UP, FALLING);
  attachInterrupt(digitalPinToInterrupt(down), DOWN, FALLING);
  attachInterrupt(digitalPinToInterrupt(right), RIGHT, FALLING);
  attachInterrupt(digitalPinToInterrupt(left), LEFT, FALLING);
  
  pixels.begin();
  ws2812fx.init();
  ws2812fx.setSpeed(200);

  menu.InitMenu((const char **)mnuRoot,cntRoot,1);
  
  //Serial.begin(115200);
  //Serial.begin(38400); // Need slower comms between atmel 32u4 and esp32
  Serial.begin(57600); // Jay mentioned this is the fastest/reliable between the two chips

  loadSettings();
  all_leds_off();
  wifi_off();
  
  genWinPayloadsMenu();
  genLinPayloadsMenu();
  genStaticStringsMenu();
}

void menu_reset(){
  mydisp.setBrightness(oledbright);
  mydisp.setFont(&defaultFont);
  mydisp.setTextScale(1);
  //all_leds_off();
}

void all_leds_off(){
  pixels.setBrightness(ledsbright);
  for(byte i=0;i<NUMPIXELS-1;i++){
    pixels.setPixelColor(i, pixels.Color(0,0,0));
    pixels.show();
    delay(5);
  }  
}

void wifi_off(){
  WiFi.mode(WIFI_OFF);
  //WiFi.forceSleepBegin();
  delay(5);
}

void menu_force_escape(){
  btnid = 4;
  btncounter++;
}


void loop()
{ 
  int keycode=0;
  int clickedItem=0; 
  
  if (btncounter > 0)
  { 
    switch(btnid)
    {
      case 1:       
        clickedItem=menu.ProcessMenu(ACTION_SELECT);
        btncounter--;
        break;
      case 2:
        menu.ProcessMenu(ACTION_DOWN);
        btncounter--;
        break;      
      case 3:
        menu.ProcessMenu(ACTION_UP);
        btncounter--;
        break;
      case 4:
        clickedItem=menu.ProcessMenu(ACTION_BACK); 
        btncounter--;
        break;
    }
  }
  
  if (clickedItem > 0)
  {
    // Logic for root menu
    if (menu.CurrentMenu==mnuRoot)
      switch (clickedItem)
      {
        case 1:
          menu.InitMenu((const char ** )mnuHIDarsenal,cntHIDarsenal,1);
          break;
        case 2:
          menu.InitMenu((const char ** )mnuWiFiPassiveTools,cntWiFiPassiveTools,1);
          break;
        case 3:
          menu.InitMenu((const char ** )mnuWiFiClient,cntWiFiClient,1);
          break; 
        case 4:
          menu.InitMenu((const char ** )mnuWiFiServer,cntWiFiServer,1);
          break; 
//        case 5:
//          menu.InitMenu((const char ** )mnuBLETools,cntBLETools,1);
//          break;
        case 5:
          menu.InitMenu((const char ** )mnuBlinky,cntBlinky,1);
          break;
        case 6:
          menu.InitMenu((const char ** )mnuGraphics,cntGraphics,1);
          break;
//        case 6:
//          menu.InitMenu((const char ** )mnuMischief,cntMischief,1);
//          break; 
        case 7:
          menu.InitMenu((const char ** )mnuExtra,cntExtra,1);
          break;
        case 8:
          menu.InitMenu((const char ** )mnuSettings,cntSettings,1);
          break;
        case 9:
          menu.InitMenu((const char ** )mnuAbout,cntAbout,1);
          break;
        case 10:
          menu.InitMenu((const char ** )mnuDebug,cntDebug,1);
          break;
      }

    // Logic for sub menus
    else if (menu.CurrentMenu==mnuHIDarsenal)
      switch (clickedItem)
      {
        case 1:
          //win kb
          menu.InitMenu((const char ** )mnuWinPayloads,cntWinPayloads,1);
          break;
        case 2:
          //lin kb
          menu.InitMenu((const char ** )mnuLinPayloads,cntLinPayloads,1);
          break;
        case 3:
          menu.MessageBox("Moving...");
          MouseJiggler();
          break;
        case 4:
          //static strings menu
          menu.InitMenu((const char ** )mnuStaticStrings,cntStaticStrings,1);
          break;
        case 5:
          GoogleAuth();
          break;
        case 6:
          break;
      }

    else if (menu.CurrentMenu==mnuWinPayloads)
      {
        runKBPayload(actualWinPayloads[clickedItem]);
      }

    else if (menu.CurrentMenu==mnuLinPayloads)
      {
        runKBPayload(actualLinPayloads[clickedItem]);
      }

    else if (menu.CurrentMenu==mnuStaticStrings)
      {
        runStaticString(actualStaticString[clickedItem]);
      }
    
    else if (menu.CurrentMenu==mnuWiFiPassiveTools)
      switch (clickedItem)
      {
        case 1:
          menu.MessageBox("Scanning...");
          AP_Channel_Usage();
          wifi_off();
          break;
        case 2:
          menu.MessageBox("Scanning...");
          AP_Scanner();
          wifi_off();
          break;
        case 3:
          Pkt_Monitor();
          //wifi_off();
          break;
        case 4:
          menu.MessageBox("Scanning...");
          Open_AP_Scanner();
          wifi_off();
          break;
        case 5:
          //DeauthMonitor();
          wifi_off();
          break;
        case 6:
          //ClientBeacons();
          //wifi_off();
          break;
      }

    else if (menu.CurrentMenu==mnuWiFiClient)
      switch (clickedItem)
      {
        case 1:
          ConnectInternet();
          break;
        case 2:
          IPConfig();
          break;
        case 3:
          NTPdisplay();
          break;
        case 4:
          menu.MessageBox("Disconnected");
          WiFi.disconnect(true);
          break;
      }

    else if (menu.CurrentMenu==mnuWiFiServer)
      switch (clickedItem)
      {
        case 1:
          APStart();
          APDisplay();
          break;
        case 2:
          APDisplay();
          break;
        case 3:
          WebServerStart();
          WebServerDisplay();
          break;
        case 4:
          WebServerDisplay();
          break;
        case 5:
          NTPstart();
          break;
        case 6:
          NTPstop();
          break;
        case 7:
          menu.MessageBox("AP off");
          APStop();
          break;
      }

//    else if (menu.CurrentMenu==mnuBLETools)
//      switch (clickedItem)
//      {
//        case 1:
//          BeaconStart();
//          break;
//        case 2:
//          BeaconStop();
//          break;
//        case 3:
//          break;
//      }

    else if (menu.CurrentMenu==mnuBlinky)
      switch (clickedItem)
      {
        case 1:
          mydisp.clearScreen();
          LED_WS2812FX_Favorites();
          break;
        case 2:
          mydisp.clearScreen();
          LED_Flashlight();
          break;
         case 3:
          mydisp.clearScreen();
          LED_WS2812FX_FullDemo();
          break;
         default:
          mydisp.clearScreen();
          byte ledmode = clickedItem - 3;
          LED_WS2812FX(ledmode);
          break; 
      }

    else if (menu.CurrentMenu==mnuGraphics)
      switch (clickedItem)
      {
        case 1:
          SelectArtwork();
          break;
        case 2:
          GfxBenchmark();
          break;
        case 3:
          cubeDemo();
          break;
        case 4:
          clockDemo();
          break;
        case 5:
          gaugeDemo();
          break;
      }

    else if (menu.CurrentMenu==mnuMischief)
      switch (clickedItem)
      {
        case 1:
          RickRollSSID();
          break;
        default:
          menu.MessageBox("N/A");
          break;
      }

    else if (menu.CurrentMenu==mnuExtra)
      switch (clickedItem)
      {
        case 1:
          snakeGame();
          break;
        case 2:
          ButtonEcho();
          break;
        case 3:
          KeyboardDemo();
          break;
      }

    else if (menu.CurrentMenu==mnuSettings)
      switch (clickedItem)
      {
        case 1:
          menu.InitMenu((const char ** )mnuOLEDBrightness,cntOLEDBrightness,1);
          break;
        case 2:
          menu.InitMenu((const char ** )mnuLEDBrightness,cntLEDBrightness,1);
          ShowLEDBrightness();
          break;
        case 3:
          if (region_unlocked == 1) {
            menu.InitMenu((const char ** )mnuRegion,cntRegion,1);
          }
          else { menu.MessageBox("Region is Locked"); }
          break;
        case 4:
          //configuration via webserver
          mydisp.clearScreen();
          mydisp.println(F("1) Start AP"));
          mydisp.println(F("2) Start Webserver"));
          mydisp.println(F("3) Browse webserver"));
          mydisp.println(F("    and nav to config"));
          mydisp.println(F("4) Reboot after mods"));
          break;
        case 5:
          SaveSettings();
          menu.MessageBox("Settings Saved");
          delay(1000);
          menu_force_escape();
          break;
        case 6:
          break;
      }

    else if (menu.CurrentMenu==mnuOLEDBrightness)
      switch (clickedItem)
      {
        case 1:
          SaveOLEDBrightness(1);
          break;
        case 2:
          SaveOLEDBrightness(2);
          break;
        case 3:
          SaveOLEDBrightness(4);
          break;
        case 4:
          SaveOLEDBrightness(7);
          break;
        case 5:
          SaveOLEDBrightness(11);
          break;
        case 6:
          SaveOLEDBrightness(15);
          break;
      }

    else if (menu.CurrentMenu==mnuLEDBrightness)
      switch (clickedItem)
      {
        case 1:
          SaveLEDBrightness(1);
          ShowLEDBrightness();
          break;
        case 2:
          SaveLEDBrightness(10);
          ShowLEDBrightness();
          break;
        case 3:
          SaveLEDBrightness(32);
          ShowLEDBrightness();
          break;
        case 4:
          SaveLEDBrightness(64);
          ShowLEDBrightness();
          break;
        case 5:
          SaveLEDBrightness(128);
          ShowLEDBrightness();
          break;
        case 6:
          SaveLEDBrightness(184);
          ShowLEDBrightness();
          break;
        case 7:
          SaveLEDBrightness(254);
          ShowLEDBrightness();
          break;
      }
    else if (menu.CurrentMenu==mnuRegion)
      switch (clickedItem)
      {
       case 1:
          menu.MessageBox("Region Set: US");
          region_id = 1;  //US
//          if (EEPROM.read(REGION_UNLOCK_ADDR)){
//            EEPROM.write(REGION_ADDR,region_id);  
//            EEPROM.commit();
//          }
          break;
       case 2:
          menu.MessageBox("Region Set: EU");
          region_id = 2;
//          if (EEPROM.read(REGION_UNLOCK_ADDR)){
//            EEPROM.write(REGION_ADDR,region_id);  
//            EEPROM.commit();
//          }
          break;      
      }

    else if (menu.CurrentMenu==mnuAbout)
      switch (clickedItem)
      {
        case 1:
          SysInfo();
          break;
        case 2:
          HWInfo();
          break;          
        case 3:
          Credits();
          break;
        case 4:
          Shouts();
          break;
      } 

    else if (menu.CurrentMenu==mnuDebug)
      switch (clickedItem)
      {
        case 1:
          DebugInfo1();
          break;
        case 2:
          all_leds_off();
          break;
        case 3:
          wifi_off();
          break;
        case 4:
          HTTPSysUpdate();
          break;
        case 5:
          RickRollSSID();
          //rotateScreen180();
          break;
        case 6:
          //loadSettings();
          //rotateScreen180();
          break;
      } 

    //after menu function, set brightness, set default font on display. reset leds
    menu_reset();
  }

  // menu return logic
  else if(clickedItem == -1){
    if (menu.CurrentMenu==mnuRoot)
      { /*In root menu already - Do Nothing*/ }

    //2nd level menus
    else if (menu.CurrentMenu==mnuHIDarsenal)   
      { menu.InitMenu((const char ** )mnuRoot,cntRoot,1); }
    else if (menu.CurrentMenu==mnuWiFiPassiveTools)   
      { menu.InitMenu((const char ** )mnuRoot,cntRoot,2); }
    else if (menu.CurrentMenu==mnuWiFiClient)
      { menu.InitMenu((const char ** )mnuRoot,cntRoot,3); }
    else if (menu.CurrentMenu==mnuWiFiServer)
      { menu.InitMenu((const char ** )mnuRoot,cntRoot,4); }
//    else if (menu.CurrentMenu==mnuBLETools)
//      { menu.InitMenu((const char ** )mnuRoot,cntRoot,5); }
    else if (menu.CurrentMenu==mnuBlinky)
      { menu.InitMenu((const char ** )mnuRoot,cntRoot,5); }
    else if (menu.CurrentMenu==mnuGraphics)
      { menu.InitMenu((const char ** )mnuRoot,cntRoot,6); }
//    else if (menu.CurrentMenu==mnuMischief)
//      { menu.InitMenu((const char ** )mnuRoot,cntRoot,6); }
    else if (menu.CurrentMenu==mnuExtra)
      { menu.InitMenu((const char ** )mnuRoot,cntRoot,7); }
    else if (menu.CurrentMenu==mnuSettings)
      { menu.InitMenu((const char ** )mnuRoot,cntRoot,8); }
    else if (menu.CurrentMenu==mnuAbout)
      { menu.InitMenu((const char ** )mnuRoot,cntRoot,9); }
    else if (menu.CurrentMenu==mnuDebug)
      { menu.InitMenu((const char ** )mnuRoot,cntRoot,10); }

    //3rd level menus
    else if (menu.CurrentMenu==mnuOLEDBrightness)
      { menu.InitMenu((const char ** )mnuSettings,cntSettings,1); }
    else if (menu.CurrentMenu==mnuLEDBrightness)
      { menu.InitMenu((const char ** )mnuSettings,cntSettings,2); 
        all_leds_off();
      }
    else if (menu.CurrentMenu==mnuRegion)
      { menu.InitMenu((const char ** )mnuSettings,cntSettings,3); }
    else if (menu.CurrentMenu==mnuWinPayloads)
      { menu.InitMenu((const char ** )mnuHIDarsenal,cntHIDarsenal,1); }
    else if (menu.CurrentMenu==mnuLinPayloads)
      { menu.InitMenu((const char ** )mnuHIDarsenal,cntHIDarsenal,2); }
    else if (menu.CurrentMenu==mnuStaticStrings)
      { menu.InitMenu((const char ** )mnuHIDarsenal,cntHIDarsenal,4); }
    

    //after return menu, reset brightness on display
    menu_reset();

   }
   
  
}

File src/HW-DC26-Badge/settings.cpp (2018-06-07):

#include "FS.h"
#include "SPIFFS.h"
#include <pgmspace.h>

#include <Adafruit_NeoPixel.h>
#include <WS2812FX.h>
#include <SSD_13XX.h>
#include <ArduinoJson.h>

#include "core.h"

extern Adafruit_NeoPixel pixels;
extern WS2812FX ws2812fx;
extern SSD_13XX mydisp;
extern volatile byte btnid;
extern byte appmode;
extern byte btncounter;

extern byte oledbright;
extern byte ledsbright;
extern byte region_id;
extern byte region_unlocked;
extern String ISSID;
extern String IPSWD;
extern int NTP_OFFSET;
extern String GOOGLEAUTH;

byte default_oledbright = 64;
byte default_ledsbright = 4;
long default_ntp_offset = -25200;
String default_oauth = "";

extern void all_leds_off();

////////////////////////////////////////////////////////////////////////////////////////////////////////

extern char itmWinPayload1[];
extern char itmWinPayload2[];
extern char itmWinPayload3[];
extern char itmWinPayload4[];
extern char itmWinPayload5[];
extern char itmWinPayload6[];
extern char itmWinPayload7[];
extern char itmWinPayload8[];
extern char itmWinPayload9[];
extern char actualWinPayloads[9][40];
void genWinPayloadsMenu()
{
  File configFile = SPIFFS.open("/win.json", "r");
  if (!configFile) { return; }

  size_t size = configFile.size();
  std::unique_ptr<char[]> buf(new char[size]);
  configFile.readBytes(buf.get(), size);
  StaticJsonBuffer<500> jsonBuffer;
  JsonObject& json = jsonBuffer.parseObject(buf.get());

  if (json.success()) {
    String t_name1 = json["NAMES"][0];
    itmWinPayload1[sizeof(t_name1)+1];
    strcpy(itmWinPayload1, t_name1.c_str());
    String t_file1 = json["FILES"][0];
    strcpy(actualWinPayloads[1], t_file1.c_str());

    String t_name2 = json["NAMES"][1];
    itmWinPayload2[sizeof(t_name2)+1];
    strcpy(itmWinPayload2, t_name2.c_str());
    String t_file2 = json["FILES"][1];
    strcpy(actualWinPayloads[2], t_file2.c_str());

    String t_name3 = json["NAMES"][2];
    itmWinPayload3[sizeof(t_name3)+1];
    strcpy(itmWinPayload3, t_name3.c_str());
    String t_file3 = json["FILES"][2];
    strcpy(actualWinPayloads[3], t_file3.c_str());

    String t_name4 = json["NAMES"][3];
    itmWinPayload4[sizeof(t_name4)+1];
    strcpy(itmWinPayload4, t_name4.c_str());
    String t_file4 = json["FILES"][3];
    strcpy(actualWinPayloads[4], t_file4.c_str());

    String t_name5 = json["NAMES"][4];
    itmWinPayload5[sizeof(t_name5)+1];
    strcpy(itmWinPayload5, t_name5.c_str());
    String t_file5 = json["FILES"][4];
    strcpy(actualWinPayloads[5], t_file5.c_str());

//    String t_name6 = json["NAMES"][5];
//    itmWinPayload6[sizeof(t_name6)+1];
//    strcpy(itmWinPayload6, t_name6.c_str());
//    String t_file6 = json["FILES"][5];
//    strcpy(actualWinPayloads[6], t_file6.c_str());
//
//    String t_name7= json["NAMES"][6];
//    itmWinPayload7[sizeof(t_name7)+1];
//    strcpy(itmWinPayload7, t_name7.c_str());
//    String t_file7 = json["FILES"][6];
//    strcpy(actualWinPayloads[7], t_file7.c_str());
//
//    String t_name8 = json["NAMES"][7];
//    itmWinPayload8[sizeof(t_name8)+1];
//    strcpy(itmWinPayload8, t_name8.c_str());
//    String t_file8 = json["FILES"][7];
//    strcpy(actualWinPayloads[8], t_file8.c_str());
//
//    String t_name9 = json["NAMES"][8];
//    itmWinPayload9[sizeof(t_name9)+1];
//    strcpy(itmWinPayload9, t_name9.c_str());
//    String t_file9 = json["FILES"][8];
//    strcpy(actualWinPayloads[9], t_file9.c_str());
  }
}

////////////////////////////////////////////////////////////////////////////////////////////////////////
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

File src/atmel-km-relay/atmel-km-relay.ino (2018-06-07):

// remix of https://github.com/spacehuhn/wifi_ducky

#include <Keyboard.h>
#include <Mouse.h>

#define PROGPIN 7
byte microdelay = 10; //built in delay no matter what

#define KEY_MENU 0xED

String bufferStr = "";
String last = "";

void RunPayload(String _line)
{
  int firstSpace = _line.indexOf(" ");
  if(firstSpace == -1) {
    Press(_line);
    Keyboard.releaseAll(); ////
  }
  else if(_line.substring(0,firstSpace) == "STRING") {
    for(int i=firstSpace+1;i<_line.length();i++) Keyboard.write(_line[i]);
  }
  else if(_line.substring(0,firstSpace) == "REPLAY" || _line.substring(0,firstSpace) == "REPEAT") {
    int replaynum = _line.substring(firstSpace + 1).toInt();
    while(replaynum)
    {
      RunPayload(last);
      --replaynum;
    }
  } 
  else if(_line.substring(0,firstSpace) == "MOUSEMOVE") {
    int x = _line.substring(firstSpace + 1).toInt();
    int y = _line.substring(firstSpace + 2).toInt();
    Mouse.move(x,y);
  }
  else if(_line.substring(0,firstSpace) == "MOUSESCROLL") {
    int wheel = _line.substring(firstSpace + 1).toInt();
    Mouse.move(0,0,wheel);  
  }
  else if(_line.substring(0,firstSpace) == "REM"){}  //shouldn't hit this scenario b/c taken care of on esp side
  else {
    String remain = _line;
    while(remain.length() > 0) {
      int latest_space = remain.indexOf(" ");
      if (latest_space == -1) {
        Press(remain);
        remain = "";
      }
      else {
        Press(remain.substring(0, latest_space));
        remain = remain.substring(latest_space + 1);
      }
      delay(5);
    }
    Keyboard.releaseAll(); ////
  }

  //Keyboard.releaseAll();
  delay(microdelay);
}

// || b.equals("")
void Press(String b){
  if(b.length() == 1) Keyboard.press(char(b[0]));

  else if (b.equals("ENTER") || b.equals("RETURN")) Keyboard.press(KEY_RETURN);
  else if (b.equals("CTRL") || b.equals("CONTROL")) Keyboard.press(KEY_LEFT_CTRL);
  else if (b.equals("SHIFT")) Keyboard.press(KEY_LEFT_SHIFT);
  else if (b.equals("ALT") || b.equals("ALT_LEFT")) Keyboard.press(KEY_LEFT_ALT);
  else if (b.equals("ALT_RIGHT")) Keyboard.press(KEY_RIGHT_ALT);
  else if (b.equals("GUI") || b.equals("WINDOWS") || b.equals("WIN")) Keyboard.press(KEY_LEFT_GUI);
  else if (b.equals("MENU")) Keyboard.press(KEY_MENU);
  else if (b.equals("UP") || b.equals("UPARROW")) Keyboard.press(KEY_UP_ARROW);
  else if (b.equals("DOWN") || b.equals("DOWNARROW")) Keyboard.press(KEY_DOWN_ARROW);
  else if (b.equals("LEFT") || b.equals("LEFTARROW")) Keyboard.press(KEY_LEFT_ARROW);
  else if (b.equals("RIGHT") || b.equals("RIGHTARROW")) Keyboard.press(KEY_RIGHT_ARROW);
  else if (b.equals("DELETE") || b.equals("DEL")) Keyboard.press(KEY_DELETE);
  else if (b.equals("PAGEUP")) Keyboard.press(KEY_PAGE_UP);
  else if (b.equals("PAGEDOWN")) Keyboard.press(KEY_PAGE_DOWN);
  else if (b.equals("HOME")) Keyboard.press(KEY_HOME);
  else if (b.equals("ESC") || b.equals("ESCAPE")) Keyboard.press(KEY_ESC);
  else if (b.equals("BACKSPACE")) Keyboard.press(KEY_BACKSPACE);
  else if (b.equals("INSERT")) Keyboard.press(KEY_INSERT);
  else if (b.equals("TAB")) Keyboard.press(KEY_TAB);
  else if (b.equals("END")) Keyboard.press(KEY_END);
  else if (b.equals("CAPSLOCK")) Keyboard.press(KEY_CAPS_LOCK);
  else if (b.equals("F1")) Keyboard.press(KEY_F1);
  else if (b.equals("F2")) Keyboard.press(KEY_F2);
  else if (b.equals("F3")) Keyboard.press(KEY_F3);
  else if (b.equals("F4")) Keyboard.press(KEY_F4);
  else if (b.equals("F5")) Keyboard.press(KEY_F5);
  else if (b.equals("F6")) Keyboard.press(KEY_F6);
  else if (b.equals("F7")) Keyboard.press(KEY_F7);
  else if (b.equals("F8")) Keyboard.press(KEY_F8);
  else if (b.equals("F9")) Keyboard.press(KEY_F9);
  else if (b.equals("F10")) Keyboard.press(KEY_F10);
  else if (b.equals("F11")) Keyboard.press(KEY_F11);
  else if (b.equals("F12")) Keyboard.press(KEY_F12);
  else if (b.equals("SPACE")) Keyboard.press(' ');
  
  else if (b.equals("MOUSECLICKLEFT") || b.equals("MOUSE_CLICK_LEFT")) Mouse.click(MOUSE_LEFT);
  else if (b.equals("MOUSECLICKRIGHT") || b.equals("MOUSE_CLICK_RIGHT")) Mouse.click(MOUSE_RIGHT);
  else if (b.equals("MOUSECLICKMIDDLE") || b.equals("MOUSE_CLICK_MIDDLE")) Mouse.click(MOUSE_MIDDLE);
  else if (b.equals("MOUSEPRESSLEFT") || b.equals("MOUSE_PRESS_LEFT")) Mouse.press(MOUSE_LEFT);
  else if (b.equals("MOUSEPRESSRIGHT") || b.equals("MOUSE_PRESS_RIGHT")) Mouse.press(MOUSE_RIGHT);
  else if (b.equals("MOUSEPRESSMIDDLE") || b.equals("MOUSE_PRESS_MIDDLE")) Mouse.press(MOUSE_MIDDLE);
  else if (b.equals("MOUSERELEASELEFT") || b.equals("MOUSE_RELEASE_LEFT")) Mouse.release(MOUSE_LEFT);
  else if (b.equals("MOUSERELEASERIGHT") || b.equals("MOUSE_RELEASE_RIGHT")) Mouse.release(MOUSE_RIGHT);
  else if (b.equals("MOUSERELEASEMIDDLE") || b.equals("MOUSE_RELEASE_MIDDLE")) Mouse.release(MOUSE_MIDDLE);
  
  //else Serial.println("not found :'"+b+"'("+String(b.length())+")");
}


void setup() { 
  pinMode(PROGPIN, OUTPUT);
  digitalWrite(PROGPIN, HIGH);  // change the tx/rx switch to have the atmel communicate with the ESP32

  Serial1.begin(57600);
  Serial.begin(57600);
  Keyboard.begin();
  Mouse.begin();
}

void loop() {  
  while (Serial.available()) {
    String serial_link = Serial.readStringUntil('\n');
          Serial1.println(serial_link);
          //Serial.println("Relaying command to connected ESP device.");
  }
  
  while (Serial1.available()) {
    String payload_line = Serial1.readStringUntil('\n');
    
    if(payload_line.length() > 0){
      payload_line.replace("\r","\n");
      payload_line.replace("\n\n","\n");
    
      while(payload_line.length() > 0){
        int latest_return = payload_line.indexOf("\n");
        if(latest_return == -1){
          RunPayload(payload_line);
          payload_line = "";
          } 
        else {
          RunPayload(payload_line.substring(0, latest_return));
          last=payload_line.substring(0, latest_return);
          payload_line = payload_line.substring(latest_return + 1);
        }
      }
    
    payload_line = "";
    }
  }

}

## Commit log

2018-06-07 Snapshot from 2018-06-03
    [l-xterm-id-ifconfig.txt, w-cmd-ipconfig-systeminfo.txt]
2018-09-16 final board design
    [HW-DC26-Badge-20180426-1.1.brd, HW-DC26-Badge-20180426-1.1.sch]
2018-09-16 note about power switch

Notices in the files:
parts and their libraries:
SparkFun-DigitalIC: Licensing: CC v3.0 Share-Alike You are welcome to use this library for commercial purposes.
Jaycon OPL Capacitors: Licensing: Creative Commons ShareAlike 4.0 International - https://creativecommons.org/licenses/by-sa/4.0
